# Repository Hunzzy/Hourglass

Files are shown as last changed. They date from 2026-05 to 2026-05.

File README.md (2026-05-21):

# Digitale Sanduhr (ESP32-C3 CodeCell)

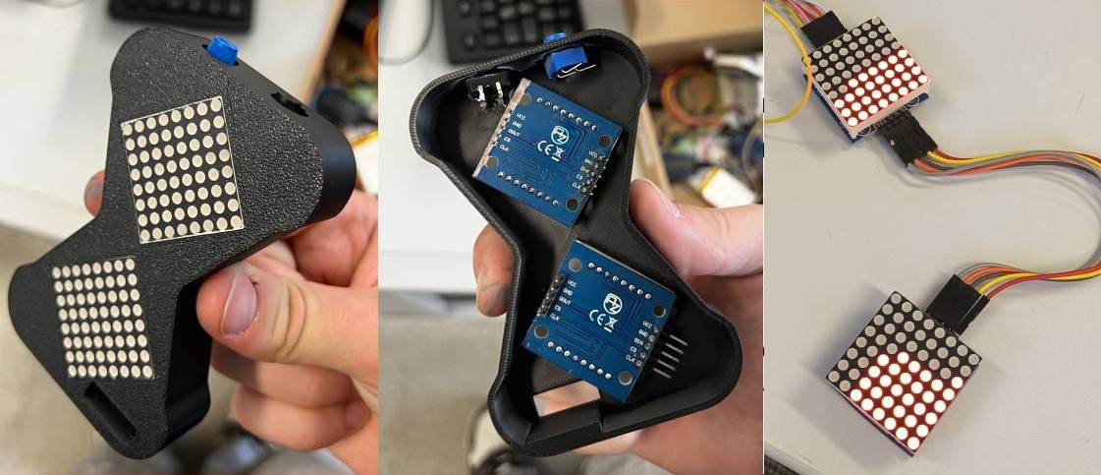
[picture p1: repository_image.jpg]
First Impression Image


Dieses Projekt realisiert eine digitale Sanduhr mit realistischer Physik-Simulation und Gravitations-Erkennung. Mithilfe der **CodeCell (ESP32-C3 Mini)** und dem integrierten **BNO085 Bewegungssensor** erkennt die Sanduhr ihre Ausrichtung und lässt den "Sand" (LED-Punkte) immer nach unten fallen.

## Features
- **Realistische Sand-Physik:** Die Sandkörner bewegen sich basierend auf der Neigung.
- **Duale Matrix-Anzeige:** Zwei kaskadierte (daisy-chained) 8x8 LED-Matrizen.
- **Präziser Timer:** Anzeige der verbleibenden Zeit auf einem TM1637 7-Segment Display.
- **Einstellbare Zeit:** Zeitwahl (1–99 Min) via Potentiometer.
- **Interaktive Steuerung:** Start/Reset über einen Taster und akustisches Feedback via Buzzer.

## Hardware-Komponenten
- **Controller:** CodeCell ESP32-C3 Mini (mit integriertem BNO085 Sensor)
- **Anzeige 1:** 2x 8x8 LED-Matrix mit MAX7219 Treibern (Daisy-Chain)
- **Anzeige 2:** TM1637 4-Digit 7-Segment Display
- **Input:** 10k Ohm Potentiometer & Momentary Push-Button
- **Output:** Aktives Buzzer-Modul (3-Pin)

## Verkabelung (Pin-Belegung)

### LED-Matrizen (MAX7219)
| Matrix Pin | ESP32-C3 Pin | Funktion |
|---|---|---|
| VCC | 4.4V (USB) | Stromversorgung |
| GND | GND | Masse |
| DIN | G7 | Data In (nur 1. Display) |
| CLK | G5 | Clock |
| CS | G6 | Chip Select |

### 7-Segment Display (TM1637)
| TM1637 Pin | ESP32-C3 Pin |
|---|---|
| CLK | G8 |
| DIO | G9 |
| VCC | 3.3V |
| GND | GND |

### Sensoren & Kontrollen
- **Potentiometer (Mitte):** G1 (ADC)
- **Taster:** G2 (Interner Pull-up genutzt)
- **Buzzer (I/O):** G3

---

## Software-Installation

### 1. Arduino IDE Vorbereitung
Stelle sicher, dass du die aktuelle [Arduino IDE](https://www.arduino.cc/en/software) installiert hast und das ESP32 Board-Paket hinzugefügt wurde:
- Gehe zu `Datei` -> `Voreinstellungen`.
- Füge unter "Zusätzliche Boardverwalter-URLs" hinzu: `https://raw.githubusercontent.com/espressif/arduino-esp32/gh-pages/package_esp32_index.json`
- Wähle unter `Werkzeuge` -> `Board` -> `ESP32` das **ESP32C3 Dev Module**.

### 2. Benötigte Bibliotheken
Installiere die folgenden Bibliotheken direkt über den **Library Manager** (`Werkzeuge` -> `Bibliotheken verwalten`):

1.  **LedControl** (von Eberhard Fahle) – Steuerung der LED-Matrizen.
2.  **TM1637** (von Avishay Orpaz) – Steuerung der 7-Segment Anzeige.
3.  **CodeCell** (von CodeCell) – Zugriff auf den internen BNO085 Sensor.

### 3. Wichtige Hinweise zum Kompilieren
- **Pfad-Fehler vermeiden:** Achte darauf, dass dein Projektordner **keine Umlaute** (ä, ö, ü) im Pfad enthält (z. B. nicht unter `C:\Benutzer\Schüler\`). Verschiebe den Ordner stattdessen nach `C:\Projekte\Sanduhr`.
- **Stromversorgung:** Da die LED-Matrizen bei voller Helligkeit viel Strom ziehen, sollte die Helligkeit im Code (`setIntensity`) niedrig eingestellt bleiben (z. B. Stufe 2), wenn die Versorgung rein über USB erfolgt.

## Bedienung
1. **Einstellen:** Drehe am Potentiometer, um die gewünschte Zeit auf dem 7-Segment Display zu sehen.
2. **Starten:** Drücke den Taster kurz. Der Sand beginnt in der oberen Matrix zu fallen.
3. **Abbrechen:** Halte den Taster für 2 Sekunden gedrückt, um zum Einstellmodus zurückzukehren.

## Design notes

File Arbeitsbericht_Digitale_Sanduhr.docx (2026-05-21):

HTL Wien 16

Thaliastraße 125 – Hettenkofergasse 15, 1160 Wien

Digitale Sanduhr

Arbeitsbericht

Klasse | 4BHEL
Schuljahr | 2025 / 2026
Schüler | Levshyn, Madl
Fach | Elektronik / Programmierung
Abgabedatum | 15.05.2026

# 1 Projektbeschreibung

## 1.1 Funktion

Die digitale Sanduhr ist ein mikrokontrollerbasiertes Gerät, das eine klassische mechanische Sanduhr elektronisch nachbildet. Der Benutzer stellt über ein Potentiometer eine Laufzeit zwischen 1 und 99 Minuten ein. Die gewählte Zeit wird auf einem 4-stelligen 7-Segment-Display im Format MM:SS angezeigt. Mit einem Tasterdruck startet der Countdown.

Während des Countdowns läuft auf zwei 8×8-LED-Matrizen eine Sand-Animation ab: Leucht-Pixel ("Sandkörner") fallen von der oberen Matrix durch einen simulierten Hals in die untere Matrix, analog zum Sand in einer echten Sanduhr. Der eingebaute Bewegungssensor (BNO085) erkennt, wenn das Gerät um 180° gedreht wird, und kehrt die Animation automatisch um.

Nach Ablauf der eingestellten Zeit ertönt ein akustisches Signal über das aktive Buzzer-Modul (5 Pieptöne, danach alle 5 Sekunden wiederholt). Ein langer Tastendruck (≥ 2 Sekunden) bricht einen laufenden Countdown jederzeit ab. Das Gerät wird über einen Akku (Lithium-Polymer) betrieben und in einem 3D-gedruckten Gehäuse untergebracht.

## 1.2 Ablaufdiagramm

EINSTELLMODUS

Potentiometer drehen → Minuten 1–99 wählen

↓ Taster kurz drücken

LAUFMODUS

Sand-Animation läuft | Display zählt MM:SS herunter | Sensor überwacht Orientierung

↓ Zeit abgelaufen ··· oder ··· Taster ≥ 2 s gehalten (Abbruch)

FERTIG-MODUS / EINSTELLMODUS

Buzzer piept • Taster drücken → Reset

# 2 Stückliste

Pos. | Bauteil / Bezeichnung | Beschreibung | Menge | Bemerkung
1 | CodeCell ESP32-C3 Mini 1 | Mikrocontroller-Modul, BNO085 integriert | 1× | Microbots
2 | 8×8 LED-Matrix MAX7219 | Rote LED-Matrix, SPI | 2× | Daisy-Chain
3 | TM1637 4-Digit Display | 7-Segment, MM:SS Anzeige | 1× | I²C-ähnlich
4 | Potentiometer | 10 kΩ, 3-polig, Dreh | 1× | Spannungsteiler
5 | Taster (Momentary) | 2-polig, Schließer | 1× | Pull-up intern
6 | Buzzer-Modul (aktiv) | 3-polig, 3.3 V | 1× | HIGH = Ton an
7 | LiPo-Akku | 3.7 V, min. 500 mAh | 1× | Stromversorgung
8 | Verbindungskabel | Jumperkabel, verschiedene Längen | ~20× | Steckverbindung
9 | 3D-Druck Gehäuse | PLA, individuell konstruiert | 1× | Sanduhr-Form

# 3 Schaltplan / Verdrahtung

Da alle Komponenten mit Jumperkabeln verbunden sind, wird die Verdrahtung in tabellarischer Form dargestellt. Die GPIO-Nummern beziehen sich auf die CodeCell ESP32-C3 Mini 1.

## 3.1 LED-Matrizen (2× MAX7219, daisy-chained)

Bauteil | Pin am Modul | GPIO (CodeCell) | Hinweis
LED-Matrix 1 & 2 | DIN (erstes) | G7 | SPI Data In
LED-Matrix 1 & 2 | CLK | G5 | SPI Clock
LED-Matrix 1 & 2 | CS / LOAD | G6 | Chip Select
LED-Matrix 1 & 2 | VCC | 4.4 V USB | Direkt an USB-Power-Pin
LED-Matrix 1 & 2 | GND | GND | Gemeinsame Masse
Kette | DOUT → DIN | — | Display 1 → Display 2

## 3.2 TM1637 4-Digit 7-Segment Display

Bauteil | Pin am Modul | GPIO (CodeCell) | Hinweis
TM1637 | CLK | G8 | Takt-Signal
TM1637 | DIO | G9 | Daten-Signal
TM1637 | VCC | 3.3 V | Spannungsversorgung
TM1637 | GND | GND | Masse

## 3.3 Potentiometer, Taster und Buzzer

Bauteil | Pin am Modul | GPIO (CodeCell) | Hinweis
Potentiometer | Linker Pin | 3.3 V | Versorgung
Potentiometer | Mittlerer Pin | G1 | ADC-Eingang (0–3.3 V)
Potentiometer | Rechter Pin | GND | Masse
Taster | Pin A | G2 | INPUT_PULLUP (kein ext. R)
Taster | Pin B | GND | Schließt auf Masse
Buzzer-Modul (aktiv) | VCC | 3.3 V | Versorgung
Buzzer-Modul (aktiv) | GND | GND | Masse
Buzzer-Modul (aktiv) | I/O | G3 | HIGH = Ton an, LOW = Ton aus

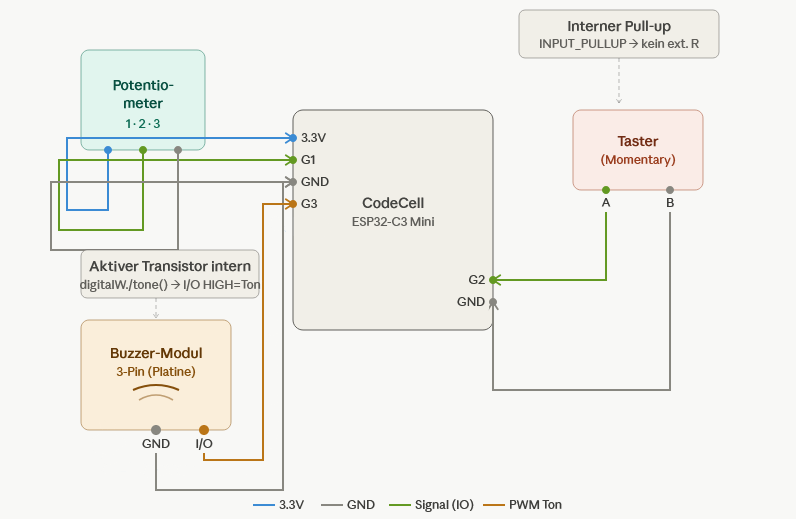
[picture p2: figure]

# 4 Verwendete Bibliotheken

Bibliothek | Autor | Installation | Verwendungszweck
MD_MAX72XX | MajicDesigns | Library Manager | Steuerung der MAX7219 LED-Matrizen via SPI
TM1637Display | Avishay Orpaz | Library Manager | 4-Digit 7-Segment Anzeige (MM:SS)
CodeCell | Microbots | Library Manager | ESP32-C3 Board-Support und BNO085 Sensor

Alle Bibliotheken sind über den Arduino Library Manager verfügbar (Sketch → Bibliotheken einbinden → Bibliotheken verwalten). Es gibt ein manuell Library zu installieren. „TM1637Display“ steht in der Github Repository zur Verfügung.

# 5 Programmcode

Der vollständige Quellcode ist in der Datei hourglass.ino zusammengefasst und in folgende logische Abschnitte gegliedert:

- Pixel-Hilfsfunktionen: Lesen und Schreiben einzelner LEDs mit Cache
- Sand-Physik (updateParticles): Simulation der Schwerkraft, Körner fallen nach unten und weichen seitlich aus
- Hals-Transfer (transferGrain): Zeitgesteuertes Übertragen eines Korns von der oberen in die untere Matrix
- Orientierungserkennung (checkOrientation): BNO085 Beschleunigung auswertet, Matrix-Rollen tauschen bei Umdrehung
- Buzzer-Steuerung: Non-blocking Piep-Sequenzen ohne delay()
- Zustands-Maschine: SETTING → RUNNING → FINISHED mit sauberem Taster-Handling

## 5.1 Quellcode (hourglass.ino)

Siehe in der GitHub Repository

# 6 Aufgabenverteilung

Aufgabe | Zuständige Person | Beschreibung
Hardwareaufbau | Levshyn & Madl | Verdrahtung aller Bauteile, Daisy-Chain der LED-Matrizen, Steckverbindungen prüfen
Gehäuse (3D-Druck) | Madl | CAD-Konstruktion des Gehäuses in Sanduhr-Form, Druck und Montage
Programmierung | Levshyn | Gesamter Arduino-Code: Sand-Physik, Buzzer, Display, Zustands-Maschine
Bibliotheken & Tests | Levshyn | Auswahl stabiler Bibliotheken, Testprogramm für alle Displays
Dokumentation | Levshyn & Madl | Gemeinsame Erstellung des Laborberichts
Präsentation | Levshyn & Madl | Gemeinsame Vorstellung des fertigen Projekts

## 6.1 Zeitplan

Phase | Zeitraum (ca.) | Tätigkeit
Planung | Woche 1 | Aufgabenanalyse
Hardware | Woche 2 | Verdrahtung aufbauen, Display-Test
Software | Woche 3 | Code schreiben, Bibliotheken testen
Integration | Woche 4 | 3D-Modell konstruieren, drucken, Hardware + Software zusammenführen, Debugging, Feinabstimmung
Gehäuse | Woche 5 | Einbau der Elektronik, Debugging
Abschluss | Woche 6 | Dokumentation fertigstellen, Präsentation vorbereiten, Abgabe

# 6 Projektphotos

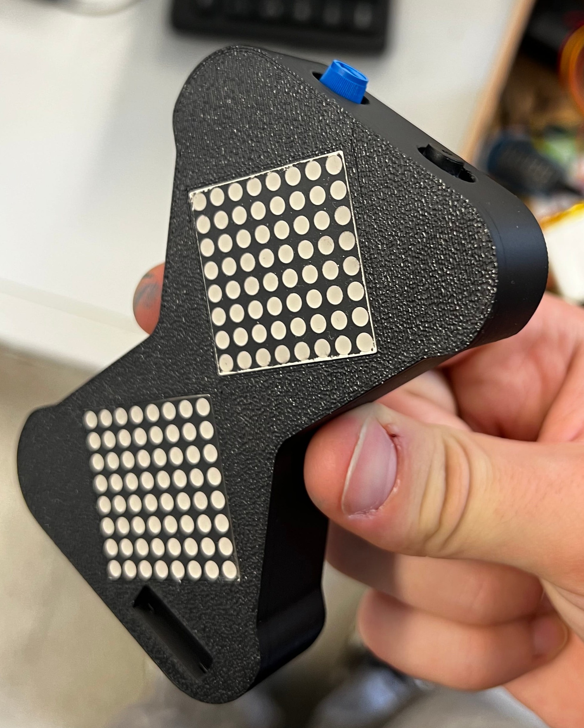
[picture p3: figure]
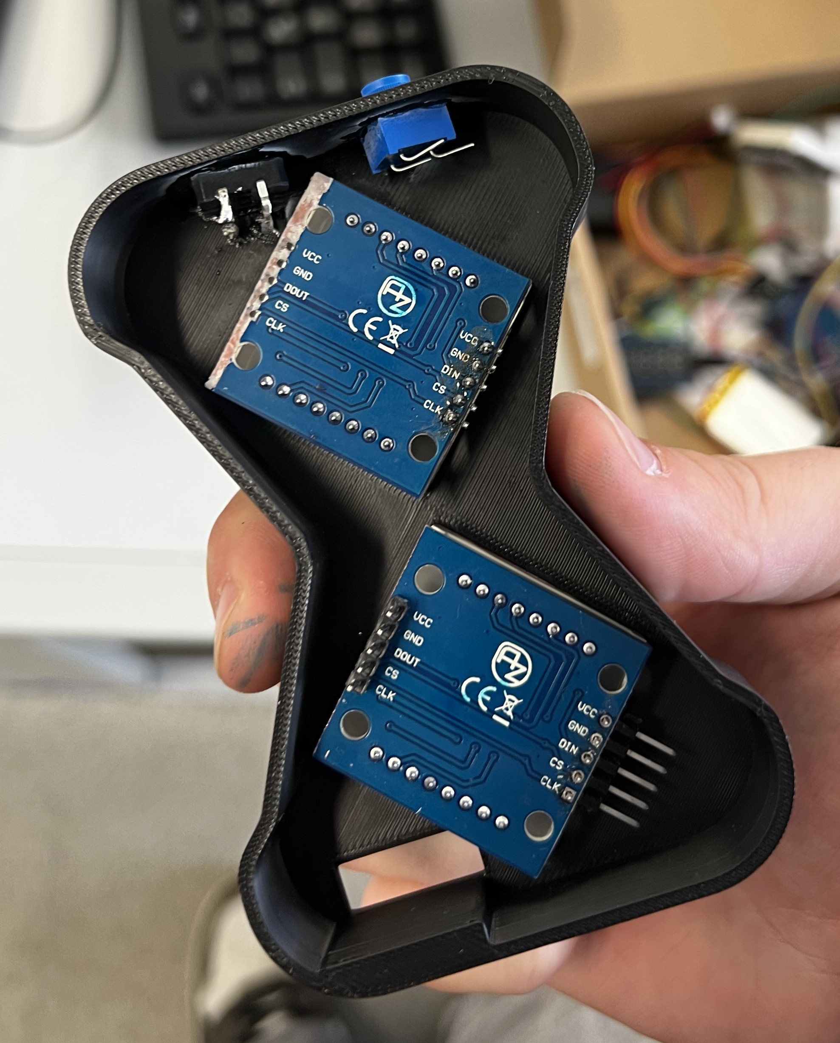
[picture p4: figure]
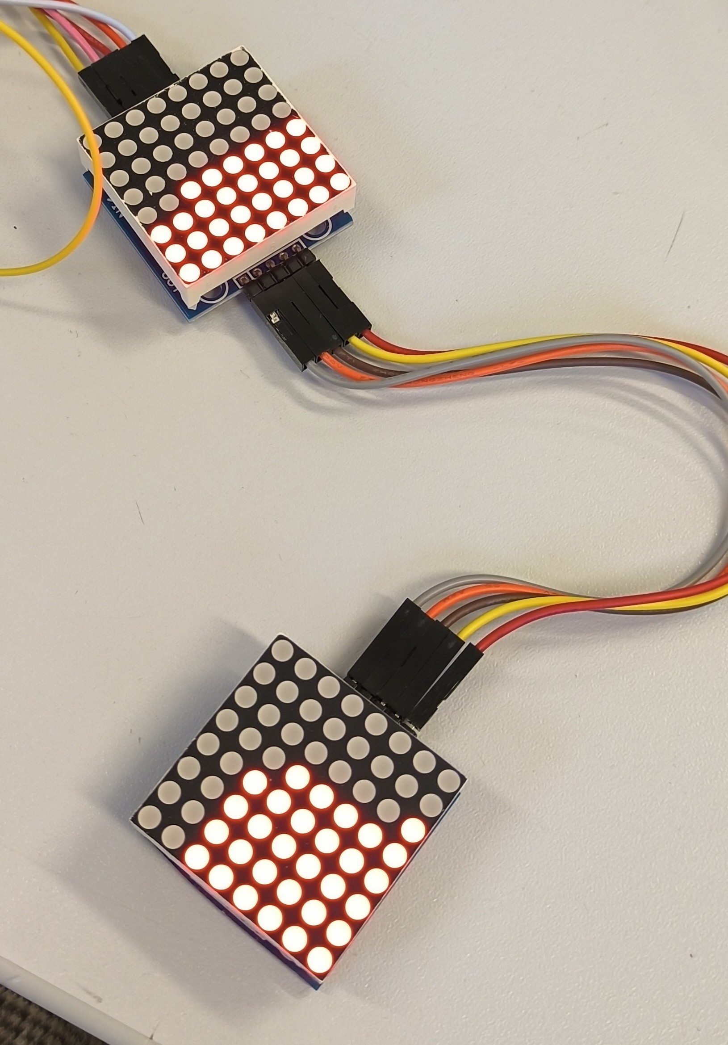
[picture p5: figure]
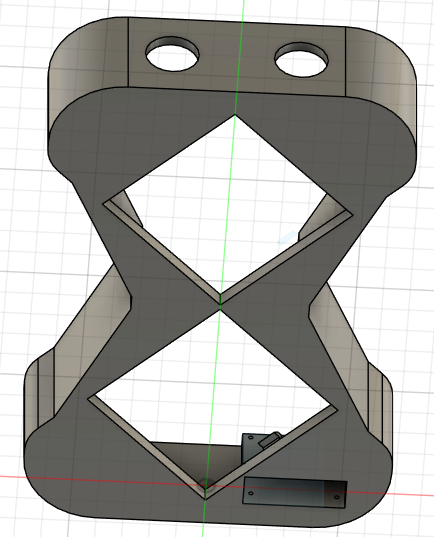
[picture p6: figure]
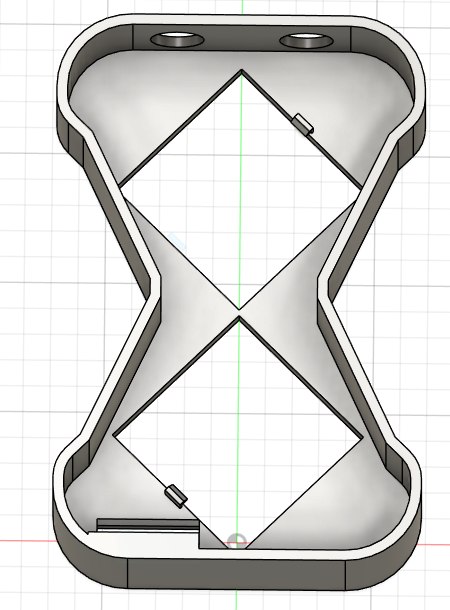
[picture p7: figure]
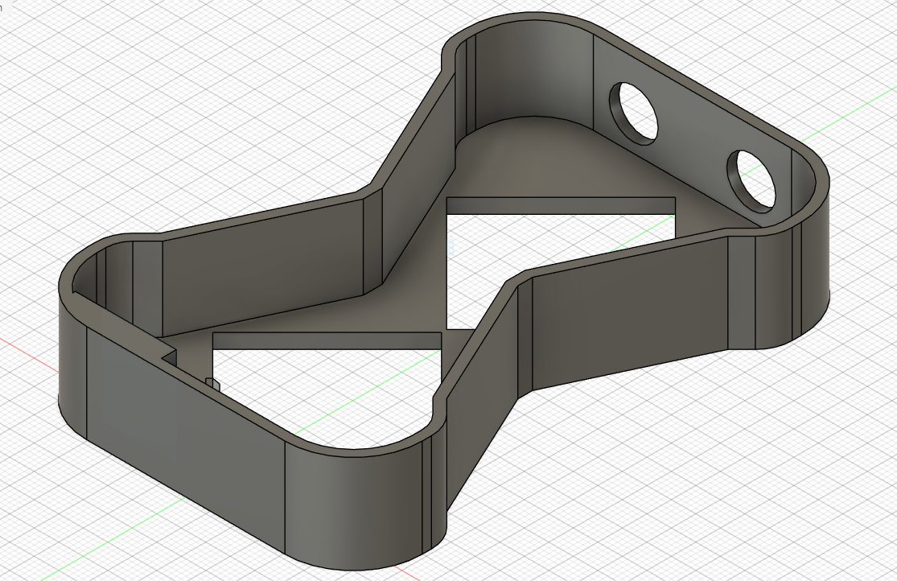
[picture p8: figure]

Seite 8 von 10

Digitale Sanduhr | 4BHEL | SJ 25/26 | Levshyn, Madl

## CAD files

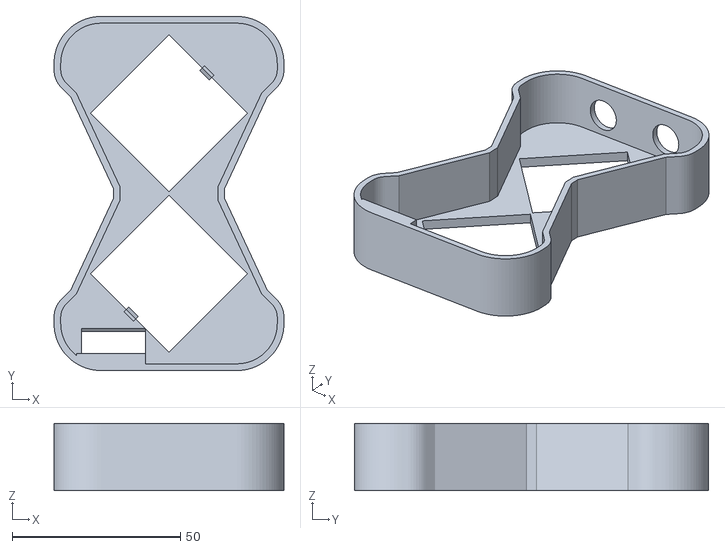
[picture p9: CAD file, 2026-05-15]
3D_Model/SchuleV1.stl
68.5 x 105.4 x 20.0

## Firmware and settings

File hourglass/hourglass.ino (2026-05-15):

/*
 * ============================================================
 * Digitale Sanduhr  –  ESP32-C3
 * 2× MAX7219 (FC-16) - OHNE SENSOR
 * Exakt 36 Körner (Perfektes Dreieck) & Gleichmäßige Verteilung
 * ============================================================
 */

#include <MD_MAX72xx.h>
#include <TM1637Display.h>

// ── Pins & Hardware ───────────────────────────────────────────
#define HARDWARE_TYPE  MD_MAX72XX::FC16_HW
#define NUM_DEVICES    2
#define PIN_DIN        7
#define PIN_CLK        5
#define PIN_CS         6

#define PIN_POT        1   // Potentiometer
#define PIN_BUTTON     2   // Taster
#define PIN_BUZZER     3   // Passiver Piezo

#define PIN_TM_CLK     8
#define PIN_TM_DIO     9

// ── Projekt-Konstanten ────────────────────────────────────────
#define MAX_GRAINS      36     // EXAKT 36 KÖRNER (füllt das obere Dreieck perfekt)
#define LONG_PRESS_MS  2000    // Langer Druck = Abbruch
#define ANIM_STEP_MS    120    // Sanfte, langsame Animation

// ── Objekte ───────────────────────────────────────────────────
MD_MAX72XX    mx(HARDWARE_TYPE, PIN_DIN, PIN_CLK, PIN_CS, NUM_DEVICES);
TM1637Display tm(PIN_TM_CLK, PIN_TM_DIO);

// ── Zustände ──────────────────────────────────────────────────
enum State { SETTING, RUNNING, FINISHED };
State state = SETTING;

// ── Globale Variablen ─────────────────────────────────────────
bool  grid[2][8][8];          
const int topDev = 0;         // Festes oberes Display
const int botDev = 1;         // Festes unteres Display

int           setMinutes  = 5;
long          remainSec   = 0;
int           grainsMoved = 0;
unsigned long grainInterval;
unsigned long grainNextMs;
unsigned long displayNextMs;
unsigned long animNextMs;     
unsigned long btnPressStart;
bool          btnWasDown  = false;

// Buzzer-Variablen für das 5-malige Piepen
int           beepCount   = 0;
bool          buzzerState = false;
unsigned long lastBuzzerToggle = 0;

float smoothedPot = 0.0f;

// ─────────────────────────────────────────────────────────────
//  Matrix-Hilfsfunktionen (inkl. 180°-Drehung für topDev)
// ─────────────────────────────────────────────────────────────

void setPixel(int dev, int col, int row, bool on) {
  if (col < 0 || col > 7 || row < 0 || row > 7) return;
  
  int pCol = col;
  int pRow = row;
  
  // Dreht Hardware-Device 0 um 180°
  if (dev == topDev) {
    pCol = 7 - col;
    pRow = 7 - row;
  }
  
  grid[dev][pCol][pRow] = on;
  mx.setPoint(pRow, dev * 8 + pCol, on);
}

bool getPixel(int dev, int col, int row) {
  if (col < 0 || col > 7 || row < 0 || row > 7) return false;
  
  int pCol = col;
  int pRow = row;
  
  if (dev == topDev) {
    pCol = 7 - col;
    pRow = 7 - row;
  }
  
  return grid[dev][pCol][pRow];
}

void clearGrids() {
  mx.clear();
  memset(grid, 0, sizeof(grid));
}

// ─────────────────────────────────────────────────────────────
//  Initialbefüllung
// ─────────────────────────────────────────────────────────────

void fillTopGrid(int n) {
  int count = 0;
  for (int diag = 0; diag <= 7 && count < n; diag++) {
    for (int dc = 0; dc <= diag && count < n; dc++) {
      int c = 7 - dc;
      int r = diag - dc;
      if (c >= 0 && c <= 7 && r >= 0 && r <= 7) {
        setPixel(topDev, c, r, true);
        count++;
      }
    }
  }
}

// ─────────────────────────────────────────────────────────────
//  Sand-Physik: OBERES DISPLAY 
// ─────────────────────────────────────────────────────────────

void updateParticlesTop() {
  for (int r = 7; r >= 0; r--) {
    for (int c = 0; c <= 7; c++) {
      if (!getPixel(topDev, c, r)) continue;

      bool canDiag = (c > 0 && r < 7) && !getPixel(topDev, c - 1, r + 1);
      bool canLeft = (c > 0)           && !getPixel(topDev, c - 1, r);
      bool canDown = (r < 7)           && !getPixel(topDev, c,     r + 1);

      if (canDiag) {
        setPixel(topDev, c,     r,     false);
        setPixel(topDev, c - 1, r + 1, true);
      } else if (canLeft && canDown) {
        if (((millis() >> 4) + c + r) & 1) {
          setPixel(topDev, c,     r, false);
          setPixel(topDev, c - 1, r, true);
        } else {
          setPixel(topDev, c,     r,     false);
          setPixel(topDev, c,     r + 1, true);
        }
      } else if (canLeft) {
        setPixel(topDev, c,     r, false);
        setPixel(topDev, c - 1, r, true);
      } else if (canDown) {
        setPixel(topDev, c,     r,     false);
        setPixel(topDev, c,     r + 1, true);
      }
    }
  }
}

// ─────────────────────────────────────────────────────────────
//  Sand-Physik: UNTERES DISPLAY 
// ─────────────────────────────────────────────────────────────

void updateParticlesBot() {
  for (int r = 7; r >= 0; r--) {
    for (int c = 7; c >= 0; c--) {
      if (!getPixel(botDev, c, r)) continue;

      bool canDiag  = (c < 7 && r < 7) && !getPixel(botDev, c + 1, r + 1);
      bool canRight = (c < 7)           && !getPixel(botDev, c + 1, r);
      bool canDown  = (r < 7)           && !getPixel(botDev, c,     r + 1);

      if (canDiag) {
        setPixel(botDev, c,     r,     false);
        setPixel(botDev, c + 1, r + 1, true);
      } else if (canRight && canDown) {
        if (((millis() >> 4) + c + r) & 1) {
          setPixel(botDev, c,     r, false);
          setPixel(botDev, c + 1, r, true);
        } else {
          setPixel(botDev, c,     r,     false);
          setPixel(botDev, c,     r + 1, true);
        }
      } else if (canRight) {
        setPixel(botDev, c,     r, false);
        setPixel(botDev, c + 1, r, true);
      } else if (canDown) {
        setPixel(botDev, c,     r,     false);
        setPixel(botDev, c,     r + 1, true);
      }
    }
  }
}

// ─────────────────────────────────────────────────────────────
//  Transfer: Korn von oben nach unten übergeben
// ─────────────────────────────────────────────────────────────

bool transferGrain() {
  int bestC = -1, bestR = -1, bestDist = 999;
  
  for (int r = 0; r <= 7; r++) {
    for (int c = 0; c <= 7; c++) {
      if (!getPixel(topDev, c, r)) continue;

      int dist = c + (7 - r);
      if (dist < bestDist) {
        bestDist = dist;
        bestC = c; bestR = r;
      }
    }
  }

  if (bestC == -1 || bestDist > 3) return false;

  int spawnC = -1, spawnR = -1;
  for (int sum = 0; sum <= 4; sum++) {
    for (int cc = 0; cc <= sum; cc++) {
      int rr = sum - cc;
      if (rr > 7 || cc > 7) continue;
      if (!getPixel(botDev, cc, rr)) {
        spawnC = cc;
        spawnR = rr;
        break;
      }
    }
    if (spawnC != -1) break;
  }

  if (spawnC == -1) return false;

  setPixel(topDev, bestC, bestR, false);
  setPixel(botDev, spawnC, spawnR, true);
  
  return true;
}

// ─────────────────────────────────────────────────────────────
//  Hilfsfunktionen
// ─────────────────────────────────────────────────────────────

void showTime(long seconds) {
  int m = seconds / 60;
  int s = seconds % 60;
  tm.showNumberDecEx((m * 100) + s, 0b01000000, true);
}

// ─────────────────────────────────────────────────────────────
//  Setup
// ─────────────────────────────────────────────────────────────

void setup() {
  Serial.begin(115200);
  
  pinMode(PIN_BUTTON, INPUT_PULLUP);
  pinMode(PIN_BUZZER, OUTPUT);
  digitalWrite(PIN_BUZZER, LOW);

  analogReadResolution(12);

  mx.begin();
  mx.control(MD_MAX72XX::INTENSITY, 2);

  tm.setBrightness(5);
  clearGrids();

  smoothedPot = (float)analogRead(PIN_POT);
  showTime((long)setMinutes * 60);
}

// ─────────────────────────────────────────────────────────────
//  Hauptschleife
// ─────────────────────────────────────────────────────────────

void loop() {
  unsigned long now = millis();
  bool btnDown = (digitalRead(PIN_BUTTON) == LOW);

  // --- Taster-Steuerung ---
  if (btnDown && !btnWasDown) {
    btnWasDown = true;
    btnPressStart = now;
  }

  if (!btnDown && btnWasDown) {
    btnWasDown = false;
    unsigned long duration = now - btnPressStart;

    if (state == SETTING) {
      // --- START COUNTDOWN ---
      tone(PIN_BUZZER, 1500, 100);
      
      remainSec = (long)setMinutes * 60;
      // Teile die Zeit exakt auf die 36 Sandkörner auf
      grainInterval = ((unsigned long)remainSec * 1000UL) / MAX_GRAINS; 
      
      grainsMoved = 0;
      clearGrids();
      fillTopGrid(MAX_GRAINS);
      
      displayNextMs = millis() + 1000UL;
      animNextMs    = millis() + ANIM_STEP_MS;
      grainNextMs   = millis() + grainInterval;
      state = RUNNING;

    } else if (state == RUNNING && duration >= LONG_PRESS_MS) {
      // --- ABBRUCH DURCH LANGEN DRUCK ---
      tone(PIN_BUZZER, 800, 400); 
      noTone(PIN_BUZZER);
      state = SETTING;
      showTime((long)setMinutes * 60);
      
    } else if (state == FINISHED) {
      // --- ZURÜCK ZUM EINSTELLEN ---
      noTone(PIN_BUZZER);
      state = SETTING;
      showTime((long)setMinutes * 60);
    }
  }

  // --- Modus: Einstellen ---
  if (state == SETTING) {
    int rawPot = analogRead(PIN_POT);
    smoothedPot = (smoothedPot * 0.92) + (rawPot * 0.08);
    
    int newMinutes = map((int)smoothedPot, 0, 4095, 1, 99);
    if (newMinutes != setMinutes) {
      setMinutes = newMinutes;
      showTime((long)setMinutes * 60);
    }
    delay(20);
  }
  
  // --- Modus: Countdown ---
  else if (state == RUNNING) {
    
    // 1. Physik updaten (flüssige, langsame Animation)
    if (now >= animNextMs) {
      animNextMs = now + ANIM_STEP_MS;
      updateParticlesTop();
      updateParticlesBot();
    }

    // 2. Sand-Transfer (Absolut gleichmäßig)
    if (now >= grainNextMs && grainsMoved < MAX_GRAINS) {
      if (transferGrain()) {
        grainsMoved++;
        // Warte das exakte Intervall ab, damit jedes der 36 Körner exakt getaktet ist
        grainNextMs = millis() + grainInterval;
      }
    }

    // 3. Display-Update (Sekundentick)
    if (now >= displayNextMs) {
      displayNextMs += 1000UL;
      
      if (remainSec > 0) {
        remainSec--;
        showTime(remainSec);
      } 
      
      if (remainSec <= 0) {
        state = FINISHED;
        beepCount = 0;            
        buzzerState = false;
        lastBuzzerToggle = millis();
      }
    }
  }
  
  // --- Modus: Beendet ---
  else if (state == FINISHED) {
    // Restliche Animation zu Ende laufen lassen
    if (now >= animNextMs) {
      animNextMs = now + ANIM_STEP_MS;
      updateParticlesTop();
      updateParticlesBot();
    }
    
    tm.showNumberDecEx(0, 0b01000000, true);
    
    // Exakt 5 Beeps abspielen und dann aufhören
    if (beepCount < 5) {
      if (now - lastBuzzerToggle >= 500) {
        lastBuzzerToggle = now;
        buzzerState = !buzzerState;
        
        if (buzzerState) {
          tone(PIN_BUZZER, 2000);
        } else {
          noTone(PIN_BUZZER);
          beepCount++; 
        }
      }
    } else {
      noTone(PIN_BUZZER); 
    }
  }
}

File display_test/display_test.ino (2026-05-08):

/*
 * ============================================================
 *  LED Display Test — ESP32-C3 Mini (CodeCell)
 * ============================================================
 *
 *  Testet:
 *    1) TM1637  → 4-Digit 7-Segment Display
 *    2) Matrix A (Adresse 0) → 8×8 LED-Matrix
 *    3) Matrix B (Adresse 1) → 8×8 LED-Matrix
 *
 *  Verdrahtung (gleich wie Sanduhr-Projekt):
 *    MAX7219: G7=DIN, G5=CLK, G6=CS, 4.4V=VCC, GND=GND
 *    TM1637:  G8=CLK, G9=DIO, 3.3V=VCC, GND=GND
 *
 *  Testablauf (Serial Monitor öffnen: 115200 Baud):
 *    Phase 1 — TM1637:   Zählt 00:00 → 00:05, zeigt "8888", dann "--:--"
 *    Phase 2 — Matrix A: Alle LEDs AN, dann AUS, dann Schachbrett
 *    Phase 3 — Matrix B: Alle LEDs AN, dann AUS, dann Schachbrett
 *    Phase 4 — Beide:    Läuft ein Pixel Zeile für Zeile durch beide Matrizen
 *    Danach: Endlosschleife mit Helligkeitstest
 * ============================================================
 */

#include "LedControl.h"
#include <TM1637Display.h>

// ── Pins ──────────────────────────────────────────────────────────────────────
#define PIN_DIN    7
#define PIN_CLK    5
#define PIN_CS     6
#define PIN_TM_CLK 8
#define PIN_TM_DIO 9

// ── Objekte ───────────────────────────────────────────────────────────────────
LedControl    lc(PIN_DIN, PIN_CLK, PIN_CS, 2);
TM1637Display tm(PIN_TM_CLK, PIN_TM_DIO);

// ── Hilfsfunktionen ───────────────────────────────────────────────────────────

void matrixAllOn(int addr) {
  for (int row = 0; row < 8; row++)
    lc.setRow(addr, row, 0xFF);
}

void matrixAllOff(int addr) {
  lc.clearDisplay(addr);
}

void matrixCheckerboard(int addr, bool invert) {
  for (int row = 0; row < 8; row++) {
    byte val = ((row % 2) == 0)
               ? (invert ? 0b01010101 : 0b10101010)
               : (invert ? 0b10101010 : 0b01010101);
    lc.setRow(addr, row, val);
  }
}

void matrixSmiley(int addr) {
  // Smiley-Gesicht
  lc.setRow(addr, 0, 0b00111100);
  lc.setRow(addr, 1, 0b01000010);
  lc.setRow(addr, 2, 0b10100101);
  lc.setRow(addr, 3, 0b10000001);
  lc.setRow(addr, 4, 0b10100101);
  lc.setRow(addr, 5, 0b10011001);
  lc.setRow(addr, 6, 0b01000010);
  lc.setRow(addr, 7, 0b00111100);
}

void matrixArrow(int addr, bool up) {
  if (up) {
    lc.setRow(addr, 0, 0b00011000);
    lc.setRow(addr, 1, 0b00111100);
    lc.setRow(addr, 2, 0b01111110);
    lc.setRow(addr, 3, 0b11111111);
    lc.setRow(addr, 4, 0b00011000);
    lc.setRow(addr, 5, 0b00011000);
    lc.setRow(addr, 6, 0b00011000);
    lc.setRow(addr, 7, 0b00011000);
  } else {
    lc.setRow(addr, 0, 0b00011000);
    lc.setRow(addr, 1, 0b00011000);
    lc.setRow(addr, 2, 0b00011000);
    lc.setRow(addr, 3, 0b00011000);
    lc.setRow(addr, 4, 0b11111111);
    lc.setRow(addr, 5, 0b01111110);
    lc.setRow(addr, 6, 0b00111100);
    lc.setRow(addr, 7, 0b00011000);
  }
}

void pause(int ms, const char* msg) {
  Serial.println(msg);
  delay(ms);
}

// ═════════════════════════════════════════════════════════════════════════════
//  SETUP
// ═════════════════════════════════════════════════════════════════════════════

void setup() {
  Serial.begin(115200);
  delay(500);
  Serial.println("========================================");
  Serial.println("  LED Display Test — Sanduhr Projekt");
  Serial.println("========================================");

  // TM1637 initialisieren
  tm.setBrightness(7);
  tm.showNumberDecEx(0, 0b01000000, true);  // "00:00"

  // MAX7219 initialisieren
  for (int i = 0; i < 2; i++) {
    lc.shutdown(i, false);
    lc.setIntensity(i, 8);
    lc.clearDisplay(i);
  }

  delay(500);

  // ══════════════════════════════════════════════════
  //  PHASE 1: TM1637 Test
  // ══════════════════════════════════════════════════
  Serial.println("\n--- PHASE 1: TM1637 (4-Digit Display) ---");

  // Zählt 00:00 bis 00:05
  Serial.println("Zähle 00:00 → 00:05 ...");
  for (int s = 0; s <= 5; s++) {
    tm.showNumberDecEx(s, 0b01000000, true);
    Serial.print("  Anzeige: 00:0"); Serial.println(s);
    delay(600);
  }

  // Alle Segmente an ("8888")
  pause(100, "Alle Segmente AN (8888) ...");
  tm.showNumberDec(8888, true);
  delay(1500);

  // Doppelpunkt blinken
  Serial.println("Doppelpunkt blinkt 4× ...");
  for (int i = 0; i < 4; i++) {
    tm.showNumberDecEx(1234, 0b01000000, false);  // mit Doppelpunkt
    delay(400);
    tm.showNumberDecEx(1234, 0b00000000, false);  // ohne Doppelpunkt
    delay(400);
  }

  // Display leer
  pause(100, "Display leer ...");
  uint8_t dashes[] = {
    SEG_G, SEG_G, SEG_G, SEG_G  // "----"
  };
  tm.setSegments(dashes);
  delay(1000);

  tm.showNumberDecEx(0, 0b01000000, true);  // zurück auf "00:00"
  Serial.println("→ TM1637 OK");

  // ══════════════════════════════════════════════════
  //  PHASE 2: Matrix A (Adresse 0)
  // ══════════════════════════════════════════════════
  Serial.println("\n--- PHASE 2: LED-Matrix A (Adresse 0) ---");

  pause(300, "Alle LEDs AN ...");
  matrixAllOn(0);
  delay(1500);

  pause(300, "Alle LEDs AUS ...");
  matrixAllOff(0);
  delay(800);

  pause(300, "Schachbrett Muster A ...");
  matrixCheckerboard(0, false);
  delay(1000);

  pause(300, "Schachbrett Muster B ...");
  matrixCheckerboard(0, true);
  delay(1000);

  pause(300, "Smiley ...");
  matrixSmiley(0);
  delay(1500);

  pause(300, "Pfeil HOCH ...");
  matrixArrow(0, true);
  delay(1200);

  matrixAllOff(0);
  Serial.println("→ Matrix A OK");

  // ══════════════════════════════════════════════════
  //  PHASE 3: Matrix B (Adresse 1)
  // ══════════════════════════════════════════════════
  Serial.println("\n--- PHASE 3: LED-Matrix B (Adresse 1) ---");

  pause(300, "Alle LEDs AN ...");
  matrixAllOn(1);
  delay(1500);

  pause(300, "Alle LEDs AUS ...");
  matrixAllOff(1);
  delay(800);

  pause(300, "Schachbrett Muster A ...");
  matrixCheckerboard(1, false);
  delay(1000);

  pause(300, "Schachbrett Muster B ...");
  matrixCheckerboard(1, true);
  delay(1000);

  pause(300, "Smiley ...");
  matrixSmiley(1);
  delay(1500);

  pause(300, "Pfeil RUNTER ...");
  matrixArrow(1, false);
  delay(1200);

  matrixAllOff(1);
  Serial.println("→ Matrix B OK");

  // ══════════════════════════════════════════════════
  //  PHASE 4: Laufpixel durch beide Matrizen
  // ══════════════════════════════════════════════════
  Serial.println("\n--- PHASE 4: Laufpixel durch Matrix A → B ---");
  lc.clearDisplay(0);
  lc.clearDisplay(1);

  for (int addr = 0; addr < 2; addr++) {
    Serial.print("  Matrix "); Serial.println(addr);
    for (int row = 0; row < 8; row++) {
      for (int col = 0; col < 8; col++) {
        lc.clearDisplay(addr);
        lc.setRawXY(addr, col, row, true);
        delay(40);
      }
    }
    lc.clearDisplay(addr);
  }
  Serial.println("→ Laufpixel OK");
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

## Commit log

2026-05-08 test program for LED Daisy Chain Displays and 4-Digit Display
2026-05-08 new testing program for buzzer, potentiometer and button / library for correct working was added
    [hourglass.ino, pot_but_buz_test.ino]
2026-05-15 Revise README for digital sand timer project
    Updated README to reflect project details for a digital sand timer with realistic physics simulation and ESP32-C3 integration.
2026-05-15 hourglass case 3D print
    [SchuleV1.stl]
2026-05-21 Describing images
    [SchuleV1.stl]
